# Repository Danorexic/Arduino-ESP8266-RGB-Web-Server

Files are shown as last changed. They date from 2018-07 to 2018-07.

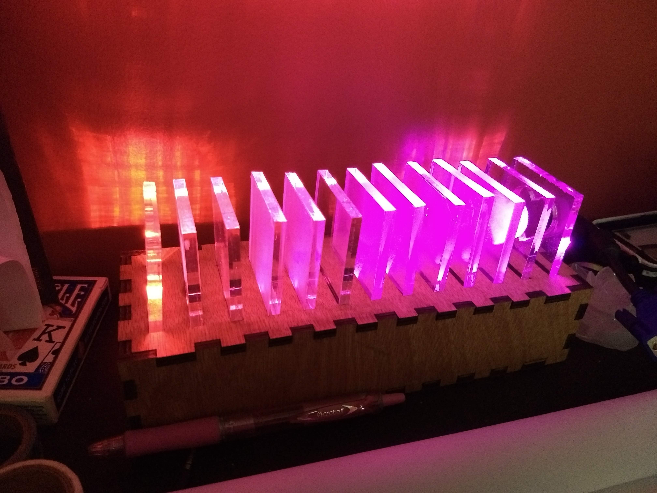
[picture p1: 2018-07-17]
Photos/Lights.jpg

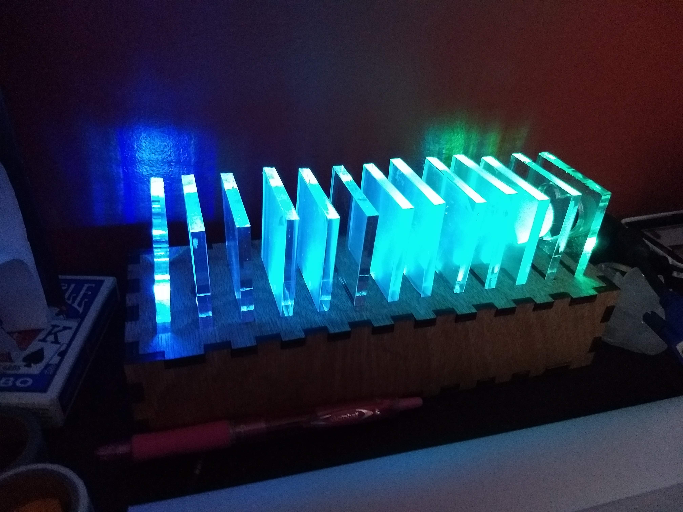
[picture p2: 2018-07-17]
Photos/Lights-2.jpg

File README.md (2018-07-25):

# Arduino-ESP8266-RGB-Web-Server-FastLED
A Wi-Fi web server for the ESP8266 platform driving a WS2812B addressable RGB Led strip - Arduino sketch

Description:
An Arduino sketch for running a Wi-Fi web server on the ESP8266-12F. Designed to drive the WS2812B addressable RGB Led strips using the FastLED Arduino library.

Updates:
I have now implemented brightness and color controls that is usable via Adafruit IO. For my setup at home, I use a toggle button for the on/off, a slider for brightness, and a textbox for the color commands. Casing not matter for the color and on/off commands. Valid brightness numbers are 0-100 and are mapped to the 0-255 the program uses. 
I've also included some photos in the photos folder of my Adafruit IO dashboard and how I've setup some of my IFTTT applets. 

Construction Notes:
This repository contains the Arduino program, HTML pages, and associated Eagle schematic and board design files. This project is forked from Giznoise's GitHub repo which I've modified extensively. I wanted to create a lightbox for my girlfriend and was able to control LED's with my Arduino but had no idea how to get them to be controlled via a webpage. Giznoise's project had this implemented wonderfully and I made adjustments along the way. I've reworked a fair bit of their program and added various features, libraries, and more. 

Changes include:
1) Changing the LED control library from Adafruit's Neopixel to the FastLED library.
2) Improving the look of the web control pages and making them better able to adjust to different screen sizes.
3) Swapping the HTML5 color picker to the JSColor javascript library. iOS devices did not support the HTML5 color picker. 
4) Adding additional web control settings to support changing blending modes, choosing different patterns, etc.
5) Added Google Assistant control support throught IFTT and Adafruit IO.
6) Created a schematic and board layout in Eagle that supports dropping in a NodeMCU v2 for controls.
7) Using a SN74AHCT125D level shifter in the schematic to enable the NodeMCU to better control the WS2812b strips. The strips need 5v signal logic and the NodeMCU provides 3.3v; this IC addresses this issue.
8) Adds Android OTA support which enables you to easily upload new programs to the NodeMCU/ESP8266 board without having to use a USB cable. 

Useful Information:
You will need to utilize the ESP8266 uploader tools to upload the data folder. You don't have to do anything special, just follow the directions for installing the tool, and just click tools, ESP8266 Sketch Data Upload and it will upload the needed files. This allows the JScolor.js file to be hosted locally on the ESP8266 vs having to host it online. A link to this tool is provided at the bottom of this page. 

Possible issues and features missing from the original project:

1) Candle mode was not converted to the FastLED library. 
2) It can be accessed via IP or via mDNS by devices on the same wifi network by typing lightbox.local in the address bar - However this feature does not function in Chrome on Android or iOS. It works in Safari on iOS and Chrome for Windows. In the future it may be possible to announce the IP address via the MQTT client but this is not implemented. The original author had similar issues and recommended finding the IP via your router admin panel. 
3) Present board design hosted on GitHub is a revision of the one I had originally gotten fabricated and has not been fabricated and tested again. It should work without issue as I only made some small tweaks to improve the board's layout.
4) The board and schematic allow for 4 LED strips to be connected but the program only supports one. I have not tested function of terminals 2-4 as of yet. The extra 3 were implemented as a future expandability option.
5) The holes for the headers for the NodeMCU to drop into are spaced according to the NodeMCU Eagle library but most NodeMCU devboard pins sort of bow out a bit. I had to bend the pins on my devboards to make them align better. 

Items to be improved:

1) A method to announce the board's IP address, likely through the MQTT client.
2) Improving the board design to directly implement an actual ESP8266 or ESP32 chip vs dropping in a NodeMCU v2 devboard. Dropping in the devboard was far easier for me to get the board design tested and up and running. 
3) Updating board design to allow for both 2.54mm and 3.5mm 3 position screw terminals, similar to how the Big Easy stepper driver allows for both sizes. 
4) Improving board design to utilize more SMD components where possible. 
5) An ESP32 version of this design for the future may be nice. 
6) Potentially splitting up the html_pages.h file into separate html pages now that I know how to store and read files from the SPIFFS.

Implements the following:

FastLED library:
https://github.com/FastLED/FastLED

Pubsubclient (MQTT) for the Google Assistant control:
https://github.com/knolleary/pubsubclient

ESP8266 Web Server:
https://github.com/esp8266/Arduino/blob/master/libraries/ESP8266WebServer/examples/AdvancedWebServer/AdvancedWebServer.ino

Using the onboard SPIFFS to store the JScolor library:
https://tttapa.github.io/ESP8266/Chap11%20-%20SPIFFS.html

ESP8266fs uploader tool:
https://github.com/esp8266/arduino-esp8266fs-plugin

JSColor javascript color picker:
http://jscolor.com/

Special thanks to:
* The original author's hard work.
* This Reddit post and guide for showing how to fix the flickering issues by using the level shifting IC:
https://www.reddit.com/r/esp8266/comments/4v24c1/d1_mini_level_converter_2812b_led_power_supply/
https://happyinmotion.com/?p=1247
* This guide on how to use Google Assistant in conjunction with IFTTT and Adafruit IO:
http://www.instructables.com/id/Control-Your-Projects-With-Google-Assistant-and-Ad/
* Countless other users on StackExchange, the Arduino Forums, and other websites whose questions and answers helped me along the way. 
* This guide on using multiple MQTT topics:
https://www.baldengineer.com/multiple-mqtt-topics-pubsubclient.html

A bill of materials for Digikey is also provided within this repository. 

Demo video viewable here: https://youtu.be/otg-TUXe8Jg

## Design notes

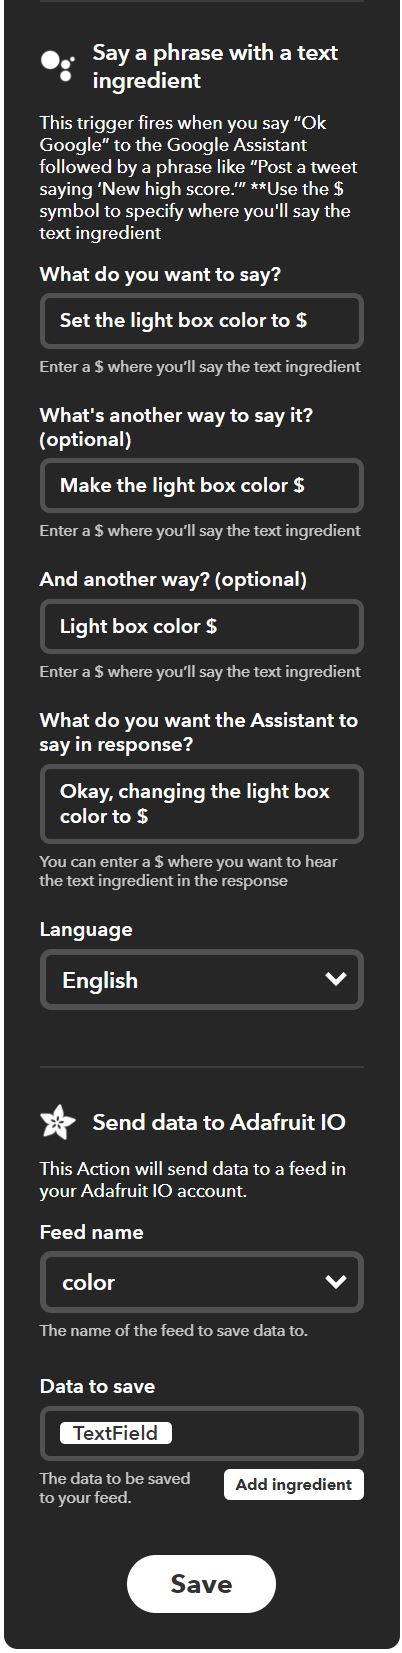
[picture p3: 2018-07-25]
Photos/IFTTT-Color.JPG

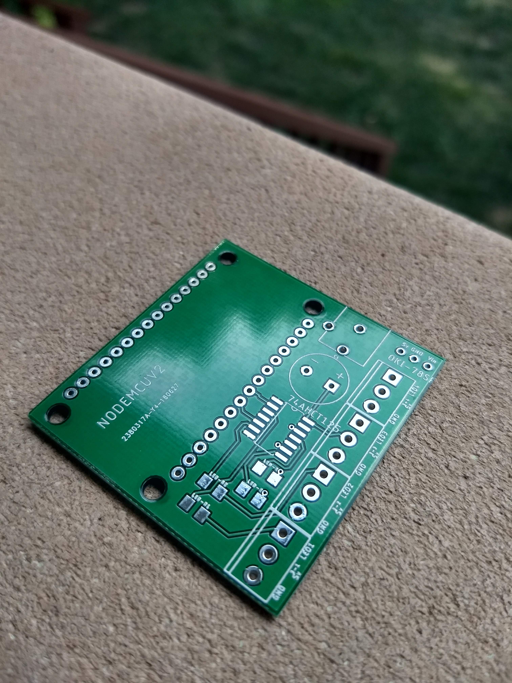
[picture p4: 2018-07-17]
Photos/PCB.jpg

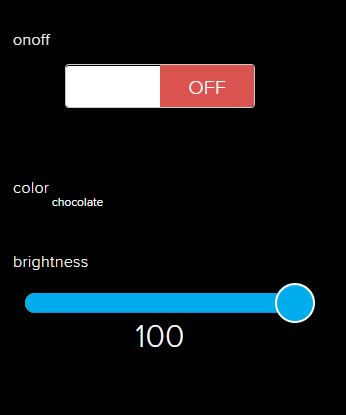
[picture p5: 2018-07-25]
Photos/AdafruitIO.JPG

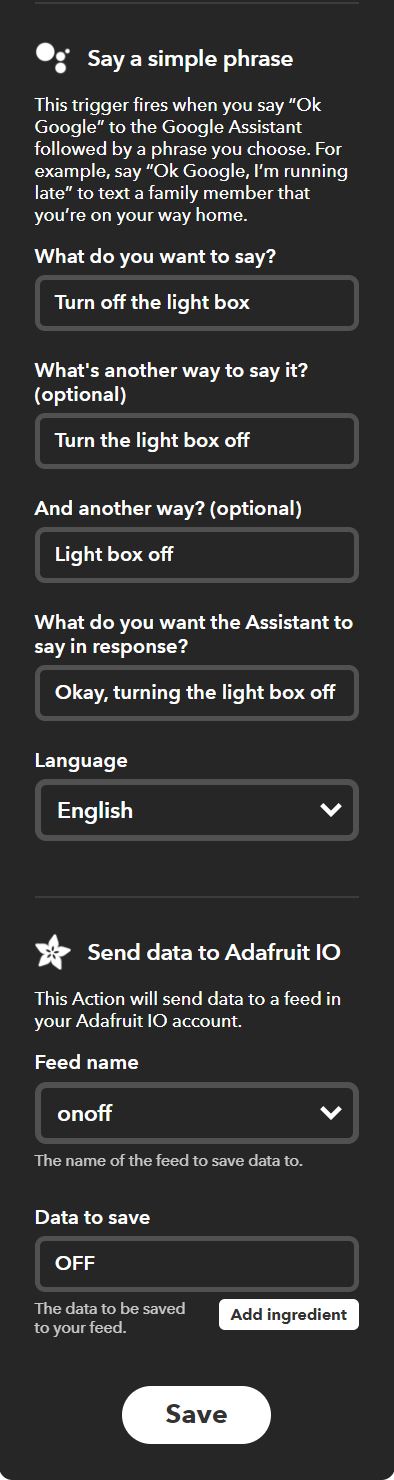
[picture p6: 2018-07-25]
Photos/IFTTT-OFF.JPG

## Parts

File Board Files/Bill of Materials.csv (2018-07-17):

Manufacturer Part Number | Manufacturer | Digi-Key Part Number | Customer Reference | Reference Designator | Packaging | Part Status | Quantity | Unit Price | Extended Price | Quantity Available | Mfg Std Lead Time | Description | RoHS Status | Lead Free Status | REACH Status
OSTTE030161 | On Shore Technology Inc. | ED2636-ND |  |  | Bulk | Active | 4 | 1.00000 | $4.00 | 3065 | 12 Weeks | TERM BLOCK 3.5MM VERT 3POS PCB | RoHS Compliant | Lead free | REACH Unaffected
PPPC151LFBN-RC | Sullins Connector Solutions | S7048-ND |  |  | Tray | Active | 2 | 1.02000 | $2.04 | 2697 | 4 Weeks | CONN HEADER FMALE 15POS .1" GOLD | RoHS Compliant | Lead free | REACH Unaffected
SN74AHCT125D | Texas Instruments | 296-4652-5-ND |  |  | Tube | Active | 1 | 0.39000 | $0.39 | 4727 | 6 Weeks | IC BUF NON-INVERT 5.5V 14SOIC | RoHS Compliant | Lead free | REACH Unaffected
PJ-102A | CUI Inc. | CP-102A-ND |  |  | Tray | Active | 1 | 0.64000 | $0.64 | 125408 | 12 Weeks | CONN PWR JACK 2X5.5MM SOLDER | RoHS Compliant | Lead free | Not Available
KTR18EZPF4700 | Rohm Semiconductor | RHM470AICT-ND |  |  | Cut Tape (CT) | Active | 4 | 0.22000 | $0.88 | 4079 | 10 Weeks | RES SMD 470 OHM 1% 1/4W 1206 | RoHS Compliant | Lead free | REACH Unaffected
UVR1E102MPD | Nichicon | 493-1065-ND |  |  | Bulk | Active | 1 | 0.46000 | $0.46 | 32853 | 25 Weeks | CAP ALUM 1000UF 20% 25V RADIAL | RoHS Compliant | Lead free | REACH Unaffected
OKI-78SR-5/1.5-W36-C | Murata Power Solutions Inc. | 811-2196-5-ND |  |  | Tray | Active | 1 | 4.30000 | $4.30 | 21476 | 30 Weeks | CONV DC/DC 7.5W 36VIN 5VOUT | RoHS Compliant | Lead free | REACH Unaffected

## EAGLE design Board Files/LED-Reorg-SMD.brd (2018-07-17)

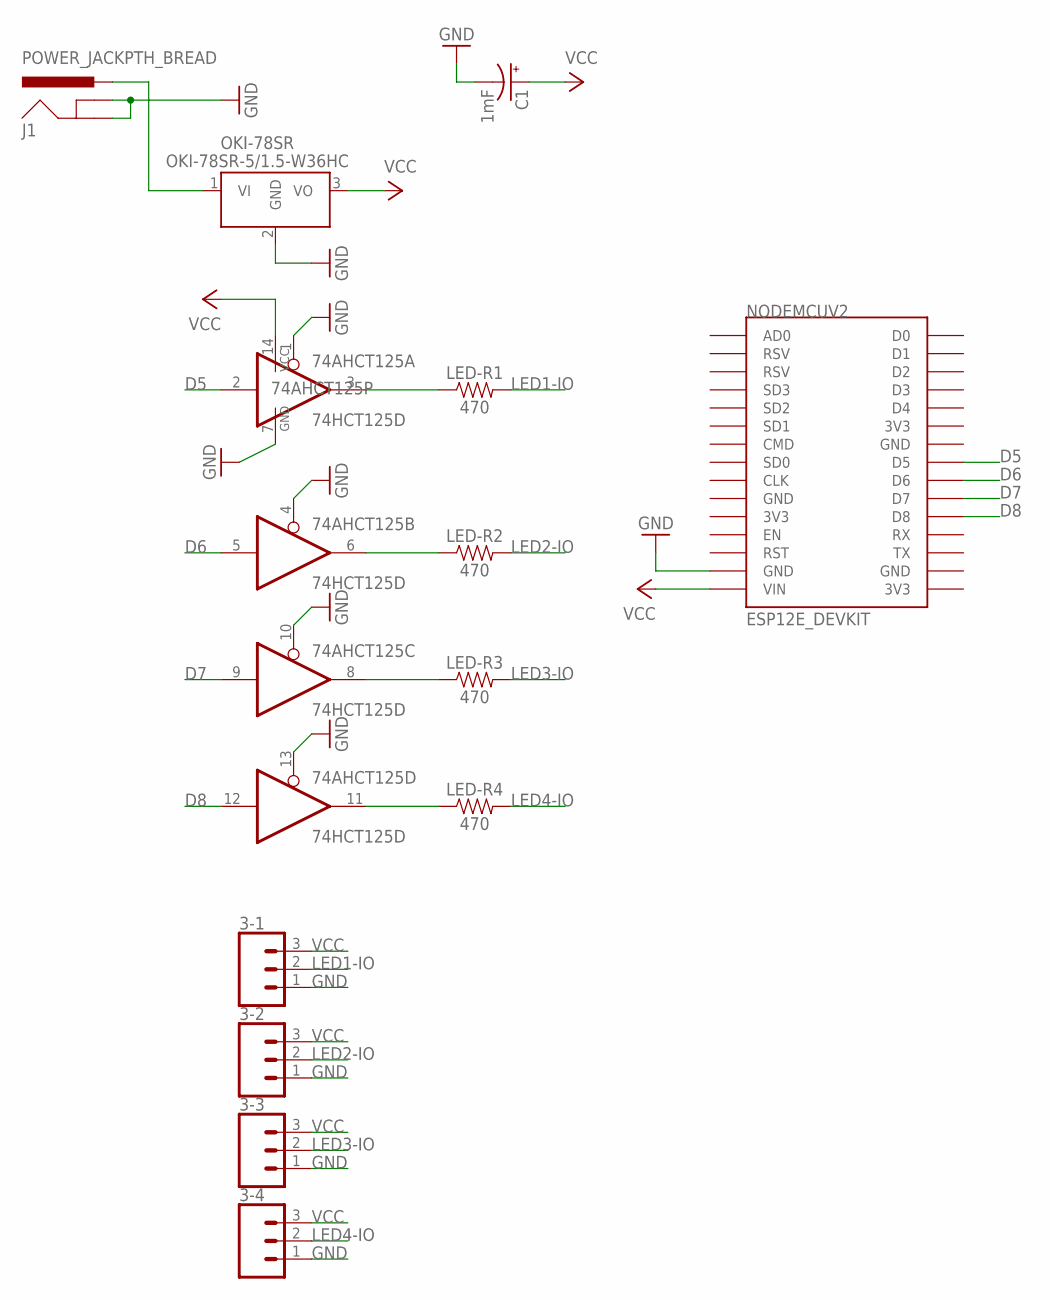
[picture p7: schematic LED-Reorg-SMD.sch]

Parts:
3-1, 3-2, 3-3, 3-4: CONN_03SCREW; SCREWTERMINAL-3.5MM-3
74AHCT125: 74HCT125D; SO14
C1: 1mF; CPOL-RADIAL-5MM-10MM
J1: POWER_JACKPTH_BREAD; POWER_JACK_PTH_BREAD
LED-R1, LED-R2, LED-R3, LED-R4: 470; 1206
NODEMCUV2: ESP12E_DEVKIT
OKI-78SR: OKI-78SR-5/1.5-W36HC; OKI-78SR_HORIZ

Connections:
D5: 74AHCT125.2 (I), NODEMCUV2.D5
D6: 74AHCT125.5 (I), NODEMCUV2.D6
D7: 74AHCT125.9 (I), NODEMCUV2.D7
D8: 74AHCT125.12 (I), NODEMCUV2.D8
GND: 3-1.1, 3-2.1, 3-3.1, 3-4.1, 74AHCT125.1 (OE), 74AHCT125.4 (OE), 74AHCT125.7 (GND), 74AHCT125.10 (OE), 74AHCT125.13 (OE), C1.-, J1.GND, J1.GNDBREAK, NODEMCUV2.GND@1 (GND), OKI-78SR.2 (GND)
LED1-IO: 3-1.2, LED-R1.2
LED2-IO: 3-2.2, LED-R2.2
LED3-IO: 3-3.2, LED-R3.2
LED4-IO: 3-4.2, LED-R4.2
unnamed: 74AHCT125.3 (O), LED-R1.1
unnamed: 74AHCT125.6 (O), LED-R2.1
unnamed: 74AHCT125.8 (O), LED-R3.1
unnamed: 74AHCT125.11 (O), LED-R4.1
unnamed: J1.PWR, OKI-78SR.1 (VI)
VCC: 3-1.3, 3-2.3, 3-3.3, 3-4.3, 74AHCT125.14 (VCC), C1.+, NODEMCUV2.VIN, OKI-78SR.3 (VO)

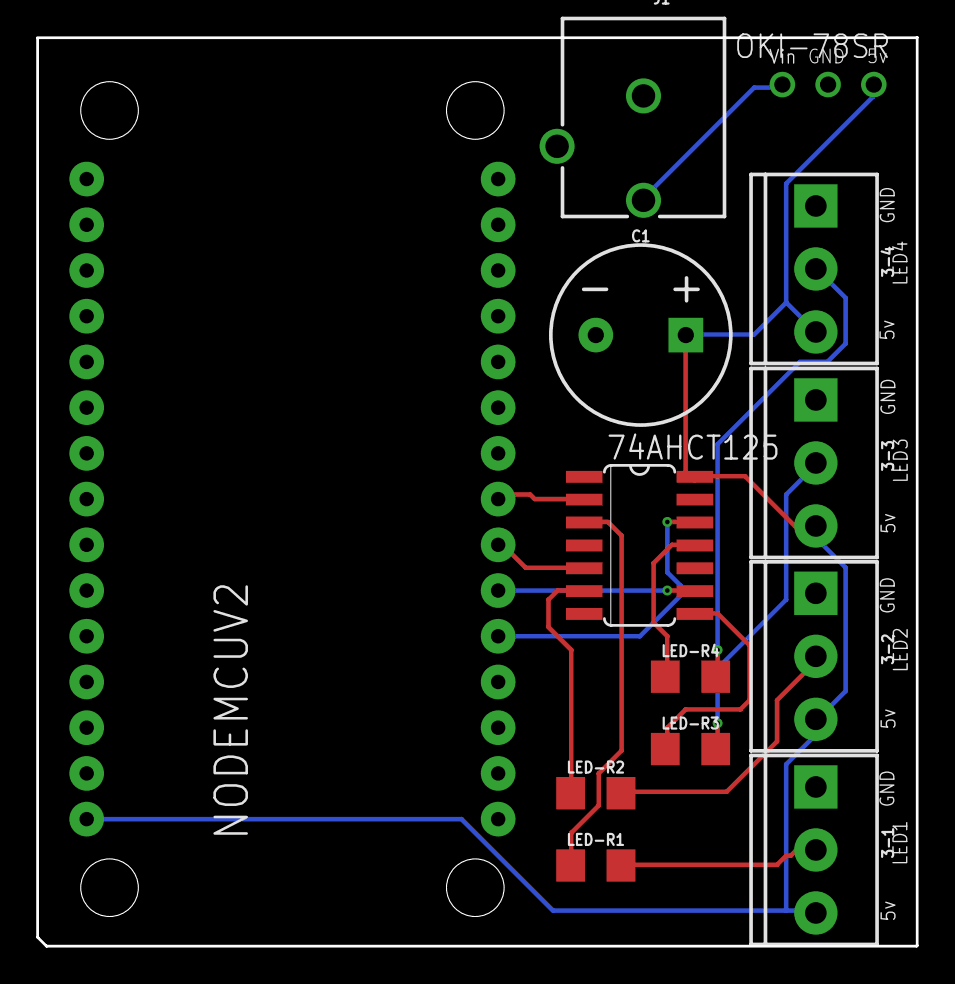
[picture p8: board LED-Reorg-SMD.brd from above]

Board: 2 copper layers, 48.9 x 50.5 mm, 13 parts (0 on the bottom side), 15 nets.

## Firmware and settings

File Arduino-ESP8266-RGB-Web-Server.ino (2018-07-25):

/*ESP8266WiFiWebServer
   Copyright (c) 2015, Majenko Technologies
   All rights reserved.
*/

/*
Original project found here https://github.com/giznoise/Arduino-ESP8266-RGB-Web-Server
*/

//Public Release Version


#include <ESP8266WiFi.h>
#include <WiFiClient.h>
#include <ESP8266WebServer.h>
#include <ESP8266mDNS.h>
#include <EEPROM.h>
#include <PubSubClient.h>
#define FASTLED_ESP8266_RAW_PIN_ORDER //Refer to FastLED notes on ESP8266 for an explanation on these modes
//This define must be called before including FastLED
#include <FastLED.h>
#include <ArduinoOTA.h>
#include "html_pages.h"
#include <FS.h>

//FastLED setup
#define LED_PIN     14
#define NUM_LEDS    13
#define LED_TYPE    WS2812B
#define COLOR_ORDER GRB
#define UPDATES_PER_SECOND 50
static uint8_t startIndex = 0;
//End FastLED defines

//MQTT Connection
#define mqtt_server "io.adafruit.com"
#define mqtt_user "Adafruit-Username"
#define mqtt_password "Adafrui API-Key"
WiFiClient espClient;
PubSubClient client(espClient);
#define control_topic "Adafirut-Username/feeds/onoff"
#define color_topic "Adafruit-Username/feeds/color"
#define brightness_topic "Adafruit-Username/feeds/brightness"

//Wifi settings
const char *ssid = "Your SSID";
const char *password = "Wifi Password";

MDNSResponder mdns;
ESP8266WebServer server ( 80 );

//FastLED stuff
CRGBPalette16 currentPalette;
TBlendType    currentBlending;

extern CRGBPalette16 myRedWhiteBluePalette;
extern const TProgmemPalette16 myRedWhiteBluePalette_p PROGMEM;

CRGB leds[NUM_LEDS];

const int delayval = 500;
String rgb_now = "#0000ff";    //global rgb state values for use in various html pages
long red_int = 0;
long green_int = 0;
long blue_int = 255;
int brightness = 255;
int mode_flag = 1;



void handleIndex();
void handleNotFound();
void handleSwitchOn();
void handleSwitchOff();
void handleSetColour();
void handleColour();
void handleSetBrightness();
void handleBrightness();
void handleSelectMode();
void handleSelectPalette(); //Select palette
void handle_mode1();
void handle_mode2();
void handle_mode3();
void handle_mode4();
void handle_mode5(); //Palette selection mode
void handle_mode6();
void light_up_all();
void turn_off_all();
//Palette select modes
void handle_cloud();
uint32_t Wheel(byte);

//Serving JS library from SPIFFS
String getContentType(String filename); // convert the file extension to the MIME type
bool handleFileRead(String path);       // send the right file to the client (if it exists)

void setup ( void ) {
  Serial.begin ( 115200 );
  //WiFi.setSleepMode(WIFI_NONE_SLEEP);
  FastLED.addLeds<LED_TYPE, LED_PIN, COLOR_ORDER>(leds, NUM_LEDS).setCorrection( TypicalLEDStrip );
  FastLED.setDither(1); //Allows for low brightness not to flicker
  //FastLED.setMaxPowerInVoltsAndMilliamps(5, 900);
  setupWiFi();

  Serial.println ( "" );

  EEPROM.begin(5);                           // set up EEPROM storage space for config values

  Serial.println ( "" );
  Serial.print ( "Connected to " );
  Serial.println ( ssid );
  Serial.print ( "IP address: " );
  Serial.println ( WiFi.localIP() );

//MQTT Setup
  client.setServer(mqtt_server, 1883);
  client.subscribe(control_topic);
  client.subscribe(color_topic);
  client.subscribe(brightness_topic);
  Serial.print("Subsribed to topic");
  client.setCallback(callback);
  Serial.print("Callback set");

//Webpage handling setup
  Serial.println ( "HTTP server started" );

  server.on ( "/", handleIndex );
  server.onNotFound ( handleNotFound );

  server.on ( "/switch_on", handleSwitchOn);
  server.on ( "/switch_off", handleSwitchOff);
  server.on ( "/set_colour", handleSetColour);
  server.on ( "/set_colour_hash", handleColour );
  server.on ( "/set_brightness", handleSetBrightness);
  server.on ( "/set_bright_val", handleBrightness);
  server.on ( "/select_mode", handleSelectMode);
  server.on ( "/select_palette", handleSelectPalette);
  server.on ( "/set_mode1", handle_mode1);
  server.on ( "/set_mode2", handle_mode2);
  server.on ( "/set_mode3", handle_mode3);
  server.on ( "/set_mode4", handle_mode4);
  server.on ( "/set_mode5", handle_mode5);
  server.on ( "/set_mode6", handle_mode6);
  server.on ( "/set_cloud", handle_cloud);
  server.on ( "/set_party", handle_party);
  server.on ( "/set_heat",  handle_heat);
  server.on ( "/set_ocean", handle_ocean);


  //EEPROM Memory//
  //Mem Location ||--0--||--1--||--2--||--3--||--4--||--5--||--6--||
  //                red   green  blue   bright  mode

  red_int = EEPROM.read(0);       //restore colour to last used value. Ensures RGB lamp is same colour as when last switched off
  green_int = EEPROM.read(1);
  blue_int = EEPROM.read(2);
  brightness = EEPROM.read(3);
  mode_flag = EEPROM.read(4);

  SPIFFS.begin();
  server.begin();

  handleSwitchOn();
}

//MQTT Callback
void callback(char* topic, byte* payload, unsigned int length){
  Serial.print("Message arrived [");
  Serial.print(topic);
  Serial.print("] ");
  String RAINBOW = String("RAINBOW");
  String RANDOM = String("RANDOM");
  payload[length] = '\0';
  String value = String((char*)payload);
  if (value.equalsIgnoreCase("On")) {
    Serial.print("ON Received!");
    handleSwitchOn();
   }
  if (value.equalsIgnoreCase("Off")){
    Serial.print("OFF Received!");
    handleSwitchOff();
  }
    if (value.equalsIgnoreCase(RAINBOW)) {
    Serial.print("RAINBOW Received!");
    handle_mode3();
  }
  if (value.equalsIgnoreCase(RANDOM)) {
    Serial.print("RANDOM Received!");
    handle_mode4();
  }


  if (strcmp(topic,brightness_topic)==0) {
    int brightness_holder = value.toInt();
    brightness = map(brightness_holder, 0, 100, 0, 255);
    FastLED.setBrightness(brightness);
    EEPROM.write(3, brightness);                   //write the brightness value to EEPROM to be restored on start-up
    EEPROM.commit();

  }
  if (strcmp(topic,color_topic)==0) {
    int x = 0; 
    for (x=0; x<26; x=x+1){
    //if (colorType[x] == value){
    if (value.equalsIgnoreCase(colorType[x])){
      Serial.print("Color received: ");
      Serial.println(value);
      Serial.print("Array value: ");
      Serial.println(colorType[x]);
      Serial.print("RGB vals: ");
      Serial.print(colorNum[x][0]);
      Serial.print(colorNum[x][1]);
      Serial.print(colorNum[x][2]);
      mode_flag = 1;   
      red_int = colorNum[x][0];
      green_int = colorNum[x][1];
      blue_int = colorNum[x][2];
      red_int = gamma_adjust[red_int];
      green_int = gamma_adjust[green_int];
      blue_int = gamma_adjust[blue_int];
      EEPROM.write(0, red_int);                 //write the colour values to EEPROM to be restored on start-up
      EEPROM.write(1, green_int);
      EEPROM.write(2, blue_int);
      EEPROM.write(4, mode_flag);                         //write mode to EEProm so can be restored on start-up
      EEPROM.commit();
      light_up_all();
      }
    }
  }
  Serial.println (value);
  for (int i=0;i<length;i++) {
    Serial.print((char)payload[i]);
    Serial.write((char)payload[i]);
  }
  Serial.println();
}

void reconnect() {
  // Loop until we're reconnected
  while (!client.connected()) {
    Serial.print("Attempting MQTT connection...");
        // Create a random client ID
    String clientId = "ESP8266Client-";
    clientId += String(random(0xffff), HEX);
    // Attempt to connect
    if (client.connect(clientId.c_str(), mqtt_user, mqtt_password)) {
      Serial.println("connected");
      client.subscribe(control_topic);
      client.subscribe(color_topic);
      client.subscribe(brightness_topic);
    } else {
      Serial.print("failed, rc=");
      Serial.print(client.state());
      Serial.println(" try again in 5 seconds");
      delay(5000);
    }
  }
}

void setupWiFi()
{
  WiFi.mode(WIFI_STA);
  WiFi.begin ( ssid, password );
  Serial.println ( "" );

  // Wait for connection
  while ( WiFi.status() != WL_CONNECTED ) {
    delay ( 500 );
    Serial.print ( "." );
  }

  //OTA update setup
  ArduinoOTA.setHostname("Lightbox-ESP8266");

  ArduinoOTA.onStart([]() {
    Serial.println("Start");
  });
  ArduinoOTA.onEnd([]() {
    Serial.println("\nEnd");
  });
  ArduinoOTA.onProgress([](unsigned int progress, unsigned int total) {
    Serial.printf("Progress: %u%%\r", (progress / (total / 100)));
  });
  ArduinoOTA.onError([](ota_error_t error) {
    Serial.printf("Error[%u]: ", error);
    if (error == OTA_AUTH_ERROR) Serial.println("Auth Failed");
    else if (error == OTA_BEGIN_ERROR) Serial.println("Begin Failed");
    else if (error == OTA_CONNECT_ERROR) Serial.println("Connect Failed");
    else if (error == OTA_RECEIVE_ERROR) Serial.println("Receive Failed");
    else if (error == OTA_END_ERROR) Serial.println("End Failed");
  });

  ArduinoOTA.begin();

  //End OTA
  //Setting up MDNS service
  delay(1000);
  if (!MDNS.begin("lightbox")) {
    Serial.println("Error setting up MDNS responder!");
    while (1) {
      delay(1000);
    }
  }
  Serial.println("mDNS responder started");
}

String getContentType(String filename) { // convert the file extension to the MIME type
  if (filename.endsWith(".js")) return "application/javascript";
  return "text/plain";
}

bool handleFileRead(String path) { // send the right file to the client (if it exists)
  Serial.println("handleFileRead: " + path);
  //if (path.endsWith("/")) path += "index.html";         // If a folder is requested, send the index file
  String contentType = getContentType(path);            // Get the MIME type
  if (SPIFFS.exists(path)) {                            // If the file exists
    File file = SPIFFS.open(path, "r");                 // Open it
    size_t sent = server.streamFile(file, contentType); // And send it to the client
    file.close();                                       // Then close the file again
    return true;
  }
  Serial.println("\tFile Not Found");
  return false;                                         // If the file doesn't exist, return false
}

void loop ( void ) {
  mdns.update();
  ArduinoOTA.handle();
  //MQTT Handling
  server.handleClient();
    if (!client.connected()) {
    reconnect();
  }
  client.loop();
  //End MQTT handling
  
  //FastLED.setBrightness(brightness);
  //currentPalette = RainbowColors_p;
  //currentBlending = LINEARBLEND;
  //startIndex = 0;
  //ChangePalettePeriodically();
  //uint8_t startIndex = 0;
  //startIndex = startIndex + 1; /* motion speed */
  //FillLEDsFromPaletteColors( startIndex);
  //FastLED.show();
  //FastLED.delay(1000 / UPDATES_PER_SECOND);

  if (mode_flag == 1) {
    FastLED.show();
    FastLED.delay(1000 / UPDATES_PER_SECOND);
  }

  if (mode_flag == 2 || mode_flag == 3) {
    static uint8_t startIndex = 0;
    startIndex = startIndex + 1; /* motion speed */

    FillLEDsFromPaletteColors( startIndex);

    FastLED.show();
    FastLED.delay(1000 / UPDATES_PER_SECOND);
  }

  if (mode_flag == 4) {
    ChangePalettePeriodically();
    static uint8_t startIndex = 0;
    startIndex = startIndex + 1; /* motion speed */

    FillLEDsFromPaletteColors( startIndex);

    FastLED.show();
    FastLED.delay(1000 / UPDATES_PER_SECOND);
  }

  if (mode_flag == 5 || mode_flag == 6) {
    static uint8_t startIndex = 0;
    startIndex = startIndex + 1; /* motion speed */

    FillLEDsFromPaletteColors( startIndex);

    FastLED.show();
    FastLED.delay(1000 / UPDATES_PER_SECOND);
  }

}

void handleIndex() {
  Serial.println ( "Request for index page received" );
  server.send ( 200, "text/html", page_contents);
}

void handleNotFound() {
  if (!handleFileRead(server.uri())) {
  String message = "File Not Found\n\n";
  message += "URI: ";
  message += server.uri();
  message += "\nMethod: ";
  message += ( server.method() == HTTP_GET ) ? "GET" : "POST";
  message += "\nArguments: ";
  message += server.args();
  message += "\n";

  for ( uint8_t i = 0; i < server.args(); i++ ) {
    message += " " + server.argName ( i ) + ": " + server.arg ( i ) + "\n";
  }

  server.send ( 404, "text/plain", message );
}
}

void handleSwitchOn() {
  mode_flag = EEPROM.read(4);                       // start-up in last saved mode
  delay(100);
  switch (mode_flag) {
    case 1: handle_mode1();
      break;
    case 2: handle_mode2();
      break;
    case 3: handle_mode3();
      break;
    case 4: handle_mode4();
      break;
    case 5: handle_mode5();
      break;
    case 6: handle_mode6();
      break;
    case 7: handle_cloud();
    default:
      light_up_all();                          //Default to fixed colour should the EEProm become corrupted
      break;
  }
  server.send ( 200, "text/html", "<SCRIPT language='JavaScript'>window.location='/';</SCRIPT>" );
};

void handleSwitchOff() {
  mode_flag = 1;                                     //go to default fixed color mode and turn off all pixels
  delay(100);
  turn_off_all();
  server.send ( 200, "text/html", "<SCRIPT language='JavaScript'>window.location='/';</SCRIPT>" );
}

void handleSetColour() {
  server.send ( 200, "text/html", colour_picker);
}


void handleSetBrightness() {
  server.send ( 200, "text/html", bright_set);
}


void handleSelectMode() {
  server.send ( 200, "text/html", mode_page );
  //  Serial.println ( "Mode select page" );
}

void handleSelectPalette() {
  server.send ( 200, "text/html", palette_page );
  //  Serial.println ( "Palette select page" );
}

void FillLEDsFromPaletteColors( uint8_t colorIndex)
{
  //uint8_t brightness = 255;

  for ( int i = 0; i < NUM_LEDS; i++) {
    leds[i] = ColorFromPalette( currentPalette, colorIndex, brightness, currentBlending);
    colorIndex += 3;
  }
}
void ChangePalettePeriodically()
{
  uint8_t secondHand = (millis() / 1000) % 60;
  static uint8_t lastSecond = 99;

  if ( lastSecond != secondHand) {
    lastSecond = secondHand;
    if ( secondHand ==  0)  {
      currentPalette = RainbowColors_p;
      currentBlending = LINEARBLEND;
      Serial.println("Second hand: ");
      Serial.println(secondHand);
    }
    if ( secondHand == 10)  {
      currentPalette = RainbowStripeColors_p;
      currentBlending = NOBLEND;
      Serial.println("Second hand: ");
      Serial.println(secondHand);

    }
    if ( secondHand == 15)  {
      currentPalette = RainbowStripeColors_p;
      currentBlending = LINEARBLEND;
      Serial.println("Second hand: ");
      Serial.println(secondHand);
    }
    if ( secondHand == 20)  {
      SetupPurpleAndGreenPalette();
      currentBlending = LINEARBLEND;
      Serial.println("Second hand: ");
      Serial.println(secondHand);
    }
    if ( secondHand == 25)  {
      SetupTotallyRandomPalette();
      currentBlending = LINEARBLEND;
      Serial.println("Second hand: ");
      Serial.println(secondHand);
    }
    if ( secondHand == 30)  {
      SetupBlackAndWhiteStripedPalette();
      currentBlending = NOBLEND;
      Serial.println("Second hand: ");
      Serial.println(secondHand);
    }
    if ( secondHand == 35)  {
      SetupBlackAndWhiteStripedPalette();
      currentBlending = LINEARBLEND;
      Serial.println("Second hand: ");
      Serial.println(secondHand);
    }
    if ( secondHand == 40)  {
      currentPalette = CloudColors_p;
      currentBlending = LINEARBLEND;
      Serial.println("Second hand: ");
      Serial.println(secondHand);
    }
    if ( secondHand == 45)  {
      currentPalette = PartyColors_p;
      currentBlending = LINEARBLEND;
      Serial.println("Second hand: ");
      Serial.println(secondHand);
    }
    if ( secondHand == 50)  {
      currentPalette = myRedWhiteBluePalette_p;
      currentBlending = NOBLEND;
      Serial.println("Second hand: ");
      Serial.println(secondHand);
    }
    if ( secondHand == 55)  {
      currentPalette = myRedWhiteBluePalette_p;
      currentBlending = LINEARBLEND;
      Serial.println("Second hand: ");
      Serial.println(secondHand);
    }
  }
}

// This function fills the palette with totally random colors.
void SetupTotallyRandomPalette()
{
  for ( int i = 0; i < 16; i++) {
    currentPalette[i] = CHSV( random8(), 255, random8());
  }
}

// This function sets up a palette of black and white stripes,
// using code.  Since the palette is effectively an array of
// sixteen CRGB colors, the various fill_* functions can be used
// to set them up.
void SetupBlackAndWhiteStripedPalette()
{
  // 'black out' all 16 palette entries...
  fill_solid( currentPalette, 16, CRGB::Black);
  // and set every fourth one to white.
  currentPalette[0] = CRGB::White;
  currentPalette[4] = CRGB::White;
  currentPalette[8] = CRGB::White;
  currentPalette[12] = CRGB::White;

}

// This function sets up a palette of purple and green stripes.
void SetupPurpleAndGreenPalette()
{
  CRGB purple = CHSV( HUE_PURPLE, 255, 255);
  CRGB green  = CHSV( HUE_GREEN, 255, 255);
  CRGB black  = CRGB::Black;

  currentPalette = CRGBPalette16(
                     green,  green,  black,  black,
                     purple, purple, black,  black,
                     green,  green,  black,  black,
                     purple, purple, black,  black );
}


// This example shows how to set up a static color palette
// which is stored in PROGMEM (flash), which is almost always more
// plentiful than RAM.  A static PROGMEM palette like this
// takes up 64 bytes of flash.
const TProgmemPalette16 myRedWhiteBluePalette_p PROGMEM =
{
  CRGB::Red,
  CRGB::Gray, // 'white' is too bright compared to red and blue
  CRGB::Blue,
  CRGB::Black,

  CRGB::Red,
  CRGB::Gray,
  CRGB::Blue,
  CRGB::Black,

  CRGB::Red,
  CRGB::Red,
  CRGB::Gray,
  CRGB::Gray,
  CRGB::Blue,
  CRGB::Blue,
  CRGB::Black,
  CRGB::Black
};
void handleColour() {
  char buf_red[3];                               //char buffers to hold 'String' value converted to char array
  char buf_green[3];
  char buf_blue[3];
  String message = server.arg(0);                //get the 1st argument from the url which is the hex rgb value from the colour picker ie. #rrggbb (actually %23rrggbb)
  rgb_now = message;
  rgb_now.replace("%23", "#");                   // change %23 to # as we need this in one of html pages
  Serial.println(rgb_now);
  //String red_val = rgb_now.substring(1, 3);      //extract the rgb values
  //String green_val = rgb_now.substring(3, 5);
  //String blue_val = rgb_now.substring(5, 7);
  String red_val = rgb_now.substring(0, 2);      //extract the rgb values
  String green_val = rgb_now.substring(2, 4);
  String blue_val = rgb_now.substring(4, 6);     //Offsetting array. JSCOLOR does not send the # with the data
  Serial.println(red_val);
  Serial.println(green_val);
  Serial.println(blue_val);
  mode_flag = 1;                                 //get to fixed colour mode if not already

  red_val.toCharArray(buf_red, 3);               //convert hex 'String'  to Char[] for use in strtol()
  green_val.toCharArray(buf_green, 3);
  blue_val.toCharArray(buf_blue, 3);

  red_int = gamma_adjust[strtol( buf_red, NULL, 16)];          //convert hex chars to ints and apply gamma adjust
  green_int = gamma_adjust[strtol( buf_green, NULL, 16)];
  blue_int = gamma_adjust[strtol( buf_blue, NULL, 16)];

  EEPROM.write(0, red_int);                 //write the colour values to EEPROM to be restored on start-up
  EEPROM.write(1, green_int);
  EEPROM.write(2, blue_int);
  //trying to fix on and off
  EEPROM.write(4, mode_flag);                         //write mode to EEProm so can be restored on start-up
  //end test
  EEPROM.commit();

  light_up_all();
  String java_redirect = "<SCRIPT language='JavaScript'>window.location='/set_colour?";
  java_redirect += message;                                                 //send hash colour value in URL to update the colour picker control
  java_redirect += "';</SCRIPT>";
  server.send ( 200, "text/html", java_redirect );                                 // all done! - take user back to the colour picking page
}

void handleBrightness() {
  String message = server.arg(0);                //get the 1st argument from the url which is the brightness level set by the slider
  String bright_val = message.substring(0, 3);   //extract the brightness value from the end of the argument in the URL
  brightness =  bright_val.toInt();
  FastLED.setBrightness(brightness);
  EEPROM.write(3, brightness);                   //write the brightness value to EEPROM to be restored on start-up
  EEPROM.commit();

  String java_redirect = "<SCRIPT language='JavaScript'>window.location='/set_brightness?";
  java_redirect += brightness;                                              //send brightness value in URL to update the slider control
  java_redirect += "';</SCRIPT>";
  server.send ( 200, "text/html", java_redirect);                                  // all done! - take user back to the brightness selection page
}

void light_up_all() {
  //FastLED
  fill_solid(leds, NUM_LEDS, CRGB(brightness * red_int / 255, brightness * green_int / 255, brightness * blue_int / 255));
  FastLED.show();
}

void turn_off_all() {
  mode_flag = 999;                                     //go to non-existent mode and turn off all pixels
  fill_solid(leds, NUM_LEDS, CRGB(0, 0, 0));
  FastLED.show();

}

void handle_mode1() {                                 //fixed colour mode
  mode_flag = 1;
  EEPROM.write(4, mode_flag);                         //write mode to EEProm so can be restored on start-up
  EEPROM.commit();
  server.send ( 200, "text/html", "<SCRIPT language='JavaScript'>window.location='/';</SCRIPT>");

  while (mode_flag == 1) {                            // Check the mode hasn't been changed whilst we wait, if so - leave immediately
    light_up_all();                           //set mode to default state - all led's on, fixed colour. This loop will service any brightness changes
    loop();                                   // Not much to do except service the main loop
  } return;
}
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

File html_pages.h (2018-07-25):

const uint16_t gamma_adjust[] {
    0,  0,  0,  0,  0,  0,  0,  0,  0,  0,  0,  0,  0,  0,  0,  0,
    0,  0,  0,  0,  0,  0,  0,  0,  0,  0,  0,  0,  1,  1,  1,  1,
    1,  1,  1,  1,  1,  1,  1,  1,  1,  2,  2,  2,  2,  2,  2,  2,
    2,  3,  3,  3,  3,  3,  3,  3,  4,  4,  4,  4,  4,  5,  5,  5,
    5,  6,  6,  6,  6,  7,  7,  7,  7,  8,  8,  8,  9,  9,  9, 10,
   10, 10, 11, 11, 11, 12, 12, 13, 13, 13, 14, 14, 15, 15, 16, 16,
   17, 17, 18, 18, 19, 19, 20, 20, 21, 21, 22, 22, 23, 24, 24, 25,
   25, 26, 27, 27, 28, 29, 29, 30, 31, 32, 32, 33, 34, 35, 35, 36,
   37, 38, 39, 39, 40, 41, 42, 43, 44, 45, 46, 47, 48, 49, 50, 50,
   51, 52, 54, 55, 56, 57, 58, 59, 60, 61, 62, 63, 64, 66, 67, 68,
   69, 70, 72, 73, 74, 75, 77, 78, 79, 81, 82, 83, 85, 86, 87, 89,
   90, 92, 93, 95, 96, 98, 99,101,102,104,105,107,109,110,112,114,
  115,117,119,120,122,124,126,127,129,131,133,135,137,138,140,142,
  144,146,148,150,152,154,156,158,160,162,164,167,169,171,173,175,
  177,180,182,184,186,189,191,193,196,198,200,203,205,208,210,213,
  215,218,220,223,225,228,231,233,236,239,241,244,247,249,252,255 };
  
  const int colorNum [26] [3] = {
    { 0, 0, 255  },
    { 0, 128, 0 },
    { 255, 0, 0 },
    { 210, 105, 30},
    { 128, 0, 128},
    { 0, 0, 128},
    { 230, 230, 250},
    { 255, 255, 0},
    { 255, 0, 255},
    { 128, 0, 0},
    { 0, 255, 255},
    { 0, 128, 128},
    { 255, 192, 203},
    { 238, 130, 238},
    { 255, 105, 180},
    { 75, 0, 130},
    { 255, 127, 80},
    { 240, 230, 140},
    { 0, 255, 0},
    { 128, 128, 0},
    { 221, 160, 221},
    { 65, 105, 225},
    { 192, 192, 192},
    { 135, 206, 235},
    { 165, 42, 42},
    { 0, 255, 255},
  
    };
  const String colorType [26] = {
    { "Blue" },
    { "Green" },
    { "Red" },
    {"Chocolate"},
    {"Purple"},
    {"Navy"},
    {"Lavender"},
    {"Yellow"},
    {"Magenta"},
    {"Maroon"},
    {"Cyan"},
    {"Teal"},
    {"Pink"},
    {"Violet"},
    {"Hot Pink"},
    {"Indigo"},
    {"Coral"},
    {"Khaki"},
    {"Lime"},
    {"Olive"},
    {"Plum"},
    {"Royal Blue"},
    {"Silver"},
    {"Sky Blue"},
    {"Brown"},
    {"Aqua"},

    };
    
const char page_contents[] PROGMEM = R"=====(
 <!doctype html>
 <html>
   <head>
     <title>Home screen</title>
     <meta name="viewport" content="width=device-width, initial-scale=1.0">
     <style type="text/css">
html, body{
    font-family: Arial;
    margin: 0;

    padding: 0;

    min-width: 100%;
    width: 100%;
    max-width: 100%;

    min-height: 100%;
    height: 100%;
    max-height: 100%;
}
#container {
    width:100%;
    height:100%;
    position:fixed;
}
#middle {height:100%;}
/*
button {
  width:100%;
  height:12%;
  -webkit-appearance:none;
  border-radius: 0;
  }
*/
button.off{
  width:100%;
  height:12%;
  -webkit-appearance:none;
  border-radius: 0;
  background:red;
  text-shadow: none;
  border: none;
  box-shadow: none;
  
}
button.on{
  width:100%;
  height:12%;
  -webkit-appearance:none;
  border-radius: 0;
  background:green;
  text-shadow: none;
  border: none;
  box-shadow: none;
}

button {
  width:100%;
  height:12%;
  -webkit-appearance: none;
	-moz-box-shadow:inset 0px 1px 0px 0px #efdcfb;
	-webkit-box-shadow:inset 0px 1px 0px 0px #efdcfb;
	box-shadow:inset 0px 1px 0px 0px #efdcfb;
	background:-webkit-gradient(linear, left top, left bottom, color-stop(0.05, #dfbdfa), color-stop(1, #bc80ea));
	background:-moz-linear-gradient(top, #cfb1e8 5%, #bc80ea 100%);
	background:-webkit-linear-gradient(top, #cfb1e8 5%, #bc80ea 100%);
	background:-o-linear-gradient(top, #cfb1e8 5%, #bc80ea 100%);
	background:-ms-linear-gradient(top, #cfb1e8 5%, #bc80ea 100%);
	background:linear-gradient(to bottom, #cfb1e8 5%, #bc80ea 100%);
	filter:progid:DXImageTransform.Microsoft.gradient(startColorstr='#cfb1e8', endColorstr='#bc80ea',GradientType=0);
	background-color:#cfb1e8;
	-moz-border-radius:0px;
	-webkit-border-radius:0px;
	border-radius:0px;
	border:1px solid #c584f3;
	display:inline-block;
	cursor:pointer;
	color:#ffffff;
	font-family:Arial;
	font-size:20px;
	font-weight:bold;
	padding:6px 24px;
	text-decoration:none;
	text-shadow:0px 1px 0px #9752cc;
}

</style>
   </head>
 <body>
 <div id="container">
   <div id="middle">
 <p align='center'><id='brightness_page'><strong style='font-size:200%'>Wifi Lightbox</strong></p>
 
 <button type='button' class='off' id='offBtn' onclick="location.href='/switch_off'">Off</button>
 
 <button type='button' class='on' id='onBtn'  onclick="location.href='/switch_on'">On</button>
 
<button type='button' id='colourBtn' onclick="location.href='/set_colour'">Set Colour</button>

<button type='button'id='brightnessBtn' onclick="location.href='/set_brightness'">Set Brightness</button>
 
<button type='button'id='modeBtn' onclick="location.href='/select_mode'">Select Mode</button>

<button type='button'id='modeBtn' onclick="location.href='/select_palette'">Select Palette</button>
</div>
</div>
</body>

</html>)=====";


const char colour_picker[] PROGMEM = R"=====(
<!DOCTYPE html>
<html>
  <head>
        <script src="jscolor.js"></script>
        <title>Color Selector</title>
        <meta name="viewport" content="width=device-width, initial-scale=1.0">
        <style type="text/css">
        /*
    button {
      width:100%;
      height:12%;
      -webkit-appearance:none;
      border-radius: 0;
      }
*/
button {
  width:100%;
  height:12%;
  -webkit-appearance: none;
	-moz-box-shadow:inset 0px 1px 0px 0px #efdcfb;
	-webkit-box-shadow:inset 0px 1px 0px 0px #efdcfb;
	box-shadow:inset 0px 1px 0px 0px #efdcfb;
	background:-webkit-gradient(linear, left top, left bottom, color-stop(0.05, #dfbdfa), color-stop(1, #bc80ea));
	background:-moz-linear-gradient(top, #cfb1e8 5%, #bc80ea 100%);
	background:-webkit-linear-gradient(top, #cfb1e8 5%, #bc80ea 100%);
	background:-o-linear-gradient(top, #cfb1e8 5%, #bc80ea 100%);
	background:-ms-linear-gradient(top, #cfb1e8 5%, #bc80ea 100%);
	background:linear-gradient(to bottom, #cfb1e8 5%, #bc80ea 100%);
	filter:progid:DXImageTransform.Microsoft.gradient(startColorstr='#cfb1e8', endColorstr='#bc80ea',GradientType=0);
	background-color:#cfb1e8;
	-moz-border-radius:0px;
	-webkit-border-radius:0px;
	border-radius:0px;
	border:1px solid #c584f3;
	display:inline-block;
	cursor:pointer;
	color:#ffffff;
	font-family:Arial;
	font-size:20px;
	font-weight:bold;
	padding:6px 24px;
	text-decoration:none;
	text-shadow:0px 1px 0px #9752cc;
}

    #container {
      width:100%;
      height:100%;
      position:fixed;
      }
    #middle {height:100%;}
    html, body{
        font-family: Arial;
        margin: 0;
    
        padding: 0;
    
        min-width: 100%;
        width: 100%;
        max-width: 100%;
    
        min-height: 100%;
        height: 100%;
        max-height: 100%;
    }
    </style>
  </head>
<body>
    <div id="container">
        <div id="middle">

      
    
<p align='center'><id='colour_page'><BR><strong style='font-size:200%'>Select a color</strong></p><BR><BR>
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

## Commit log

2018-07-17 Pushing current revision
    Initial release of forked project
    [Bill of Materials.csv, LED-Reorg-SMD.brd, LED-Reorg-SMD.sch]
2018-07-17 Renaming files
    Renaming files to that .INO matches folder name to comply with Arduino compile requirements.
2018-07-17 Including photos
    Attaching photos of fabricated PCB
2018-07-17 ESP8266 File Upload Tool
    Mentioned the link at the bottom of the page for uploading the data folder to the board's SPIFFS.

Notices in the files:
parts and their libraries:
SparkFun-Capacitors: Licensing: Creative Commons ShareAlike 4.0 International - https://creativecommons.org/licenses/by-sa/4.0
